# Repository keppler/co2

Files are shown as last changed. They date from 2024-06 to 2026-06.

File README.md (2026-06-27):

# CO₂-Sensor für Höhlen



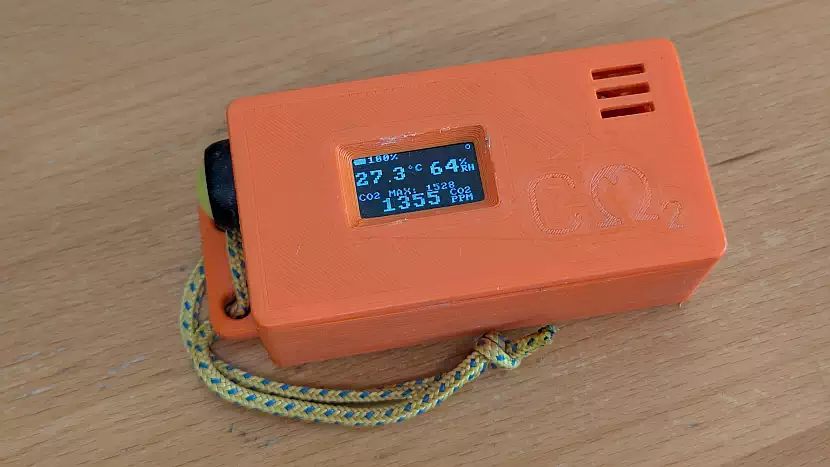
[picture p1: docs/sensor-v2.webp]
fertiger CO₂-Sensor


## Hintergrund

Kohlenstoffdioxid (_CO₂_) spielt bei der Entstehung von Höhlen eine zentrale Rolle. In Wasser gelöst - als Kohlensäure
(_H₂CO₃_) - kann es Kalk aufnehmen und somit Hohlräume entstehen lassen. Anders herum wachsen Tropfsteine, wenn mit
Kalziumkarbonat gesättigte Kohlensäure in einem Hohlraum wieder _CO₂_ an die Umgebungsluft abgibt und sich der
überschüssige Kalk absetzt. Unterirdische Wasserläufe können unter bestimmten Bedingungen ebenfalls _CO₂_ einbringen,
auch biologische und chemische Prozesse können unter Tage _CO₂_ erzeugen.

## Problem

Kohlenstoffdioxid ist ein geruchs-, geschmacks- und farbloses Gas. Zu hohe Konzentrationen sind für den menschlichen
Körper lebensgefährlich. In einigen Höhlen können sich - je nach Bewetterung, Vegetation und Jahreszeit - durchaus
bedrohliche _CO₂_-Konzentrationen bilden. In den meisten betroffenen Höhlen ist eine eventuelle _CO₂_-Problematik
bekannt und in der Regel wird auf Höhlenplänen oder vor Ort darauf hingewiesen. Befährt man jedoch eine bis dato
unbekannte Höhle oder möchte die tatsächlichen Werte messen, ist es gut, ein entsprechendes Messgerät zu haben. :-)

Handelsübliche (günstige) _CO₂_-Messgeräte für die Raumluftqualität messen nur bis 2.000 oder 5.000 ppm (0,2% bzw. 0,5%).
In entsprechenden Höhlen sind Werte über 20.000 ppm (2%) aber keine Seltenheit. Rettungskräfte, Berg- und
Industriearbeiter nutzen professionelle _CO₂_-Warngeräte (z.B. _Dräger Pac® 8000_ oder _CO2Meter PRO-10_) - für Privatpersonen sind diese aber
schwer erhältlich und zudem ziemlich kostspielig. Der häufig durchgeführte "Flammentest" (mit Feuerzeug prüfen ob eine
Flamme erzeugt werden kann) ist viel zu ungenau und zu gefährlich - eine Flamme erlöscht meist erst unter 16% Sauerstoff,
was schon auf eine _CO₂_-Konzentration von >50.000 ppm hindeuten kann!

## Lösung

Die hier vorgestellte Schaltung soll eine günstige Messung der Kohlenstoffdioxid-Konzentration auch in hohen
Bereichen ermöglichen - zuverlässiger als ein "Flammen-Test", und dennoch bezahlbar.

> [!CAUTION]
> Der Sensor darf dennoch nur als **zusätzlicher** Indikator angesehen werden! Die üblichen Anzeichen eines zu hohen
> _CO₂_-Gehalts müssen unabhängig davon beobachtet werden. Machen Sie Ihr Leben nicht von der korrekten Funktion eines
> einzelnen Sensors abhängig!  
> Zudem ersetzt diese Schaltung unter keinen Umständen ein professionelles Messgerät, das regelmäßig gewartet und
> kalibriert wird!

### Der Sensor

In den letzten Jahren hat sich in der Entwicklung von _CO₂_-Sensoren viel getan - nicht zuletzt aufgrund der
Corona-Pandemie. Der Sensor [SCD41](https://sensirion.com/de/produkte/katalog/SCD41) der Schweizer _Sensirion AG_ nutzt
das photo-akustische NDIR-Verfahren, um auf kleinstem Raum (rund 10x10x6 mm) den Anteil von _CO₂_-Molekülen in der
Umgebungsluft zu bestimmen.
Sofern die Membran des Sensors nicht zu stark verschmutzt wird, ist der Sensor technisch bedingt äußerst lange haltbar.
Die regelmäßige Kalibrierung kann automatisch anhand des _CO₂_-Gehalts in freier Umgebung erfolgen (etwa 400 ppm).

### Der Mikrocontroller

Als Mikrocontroller zur Ansteuerung des Sensors und des Displays dient ein simpler [ATtiny85](https://www.microchip.com/en-us/product/attiny85). Dieser ist robust,
günstig, gut verfügbar und mit vergleichsweise einfachen Mitteln programmierbar. Nutzt man seinen Funktionsumfang
voll aus, kann dieser ohne weitere Hilfsmittel auch die Batteriespannung messen und benötigt im Standby weniger
Strom als die Selbstentladung der Batterie.

### Das Display

Zur Anzeige dient ein schlichtes OLED-Display vom Typ _SSD1306_. Auch dieses ist günstig, gut verfügbar und einfach
zu programmieren. Zudem ist das Display - wie der Sensor auch - über einen I²C-Bus ansteuerbar, was die Verdrahtung
dramatisch vereinfacht.

## Die Schaltung

### Variante "Minimalistisch"

Für den ersten Prototypen reicht eine simple Lochrasterplatine, da im Prinzip nur die Stromversorgung und der I²C-Bus
vom Controller zum Sensor und Display (parallel) durchverdrahtet werden müssen:

<!-- ![Bild des ersten Sensor-Prototypen im Einsatz](https://github.com/keppler/co2/raw/master/docs/sensor.webp) -->

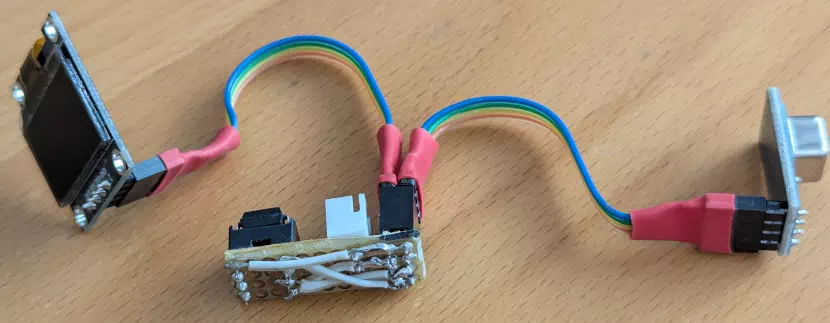
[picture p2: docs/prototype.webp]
einfacher Prototyp


### Variante "Komfort" (Version 1.3)

Die "Komfort-Schaltung" nutzt darüber hinaus noch die restlichen Pins, um einen Piezo-Piepser zur Alarmierung sowie
eine Taste zur Konfiguration zu integrieren. Hierfür wurde eine Platine gestaltet, um alle Komponenten ordentlich
zu platzieren.

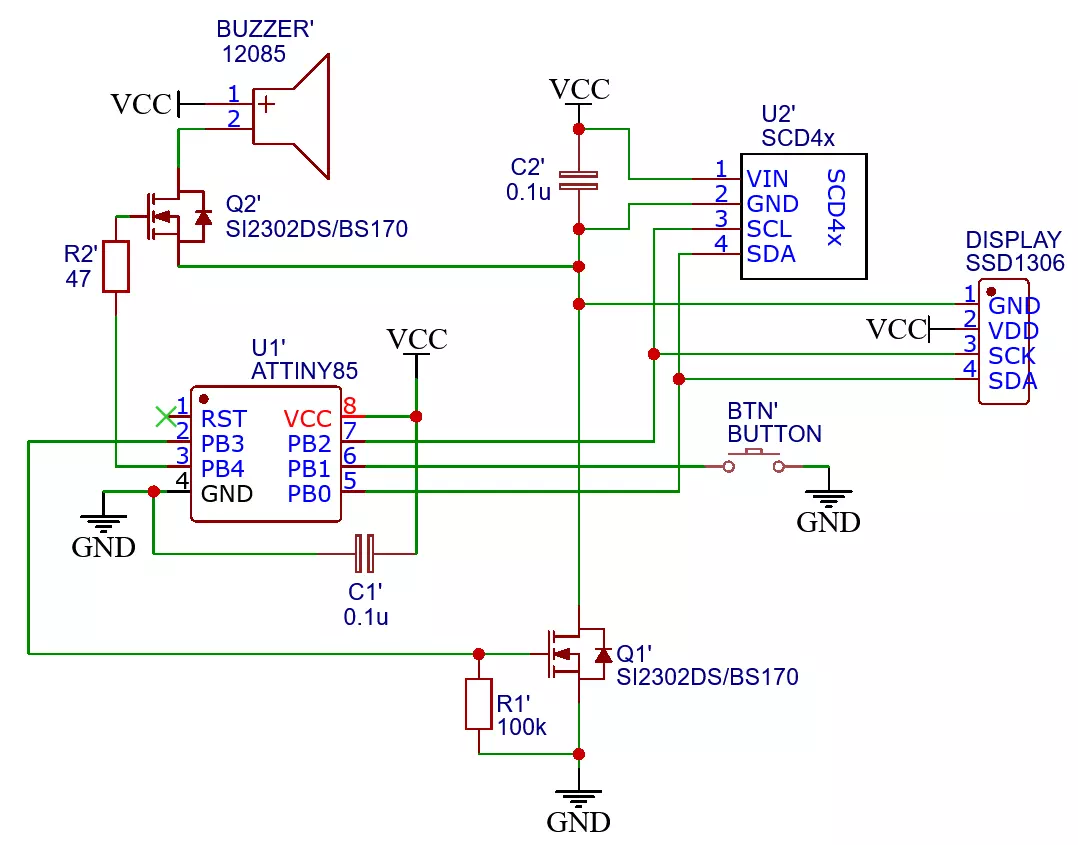
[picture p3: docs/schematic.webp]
Schaltplan


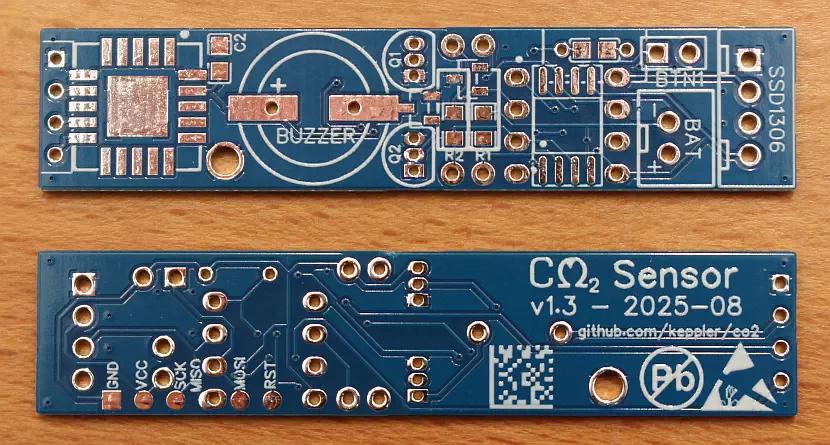
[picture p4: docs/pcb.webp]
Platine


Die Platine kann per SMD oder "klassisch" mit Lötkolben bestückt werden.

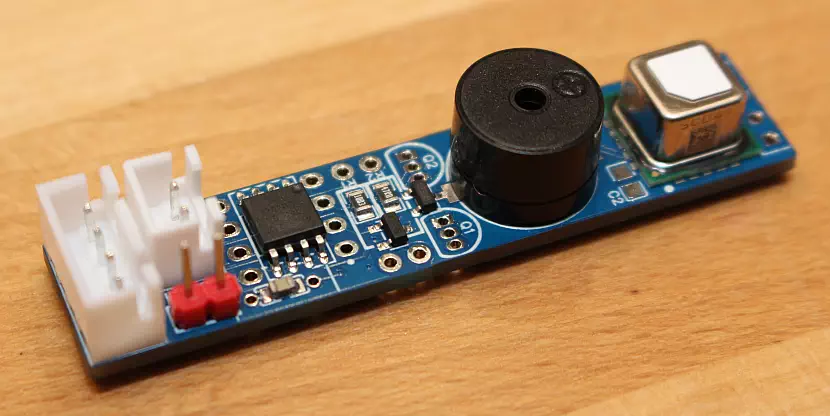
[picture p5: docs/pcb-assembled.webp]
SMD-bestückte Platine


### Bauteilliste

| Bezeichnung | Bauteil |
|---|---|
| U1 | ATtiny85 |
| U2 | SCD41 |
| Q1, Q2 | SI2302DS oder BS170 |
| R1 | Widerstand 100kΩ |
| R2 | Widerstand 47Ω |
| C1 | Kondensator 0.1µF |
| C2 | _entfällt_ |
| DISPLAY | 0,96" OLED-Display SSD1306 (I²C!) |
| BUZZER | 12x8.5mm passive Buzzer Typ 12085 |

### Bezugsquellen

Nahezu alle Teile sind bei jedem gut sortierten Elektronikdistributor bestellbar, die meisten Teile lassen sich auch
über eBay oder AliExpress besorgen. Nur beim Sensor sollte man etwas aufpassen: bei AliExpress werden diese sowohl "lose"
als auch auf kleinen Breakout-Platinen für rund $20 verkauft. Ich habe ein halbes Dutzend solcher Sensoren von
verschiedenen AliExpress-Händlern gekauft - interessanterweise hatten alle _keine_ aufgelaserte Seriennummer. Es wird
vermutet, dass es sich hierbei um Exemplare handelt, die aus anderen Produkten/Schaltungen ausgebaut wurden. Auch diese
Sensoren lieferten plausible Daten (ich glaube also nicht dass das "Kopien" sind), aber da es kaum eine Ersparnis
gegenüber einem offiziellen Distributor gibt, würde ich da eher die Finger von lassen.

Die Platine kann man sich mit den hier im Repository hinterlegten Gerber-Dateien bei jedem beliebigen Auftragsfertiger
erstellen lassen, z.B. bei JLCPCB oder Elecrow.

Ich habe normalerweise immer die eine oder andere Platine "übrig" - ein offizieller Verkauf ist aufgrund der Elektronikregulierung
aber nicht möglich. Bei Interesse bitte kurze Mail an `klaus (at) fund-ev.de`.

### Gehäuse

Ein passendes Gehäuse kann bequem mit einem 3D-Drucker erstellt werden, die `.stl`-Druckdateien liegen im Verzeichnis `case/`. PLA-Filament ist meistens völlig ausreichend, ABS ist natürlich robuster (aber auch schwieriger zu drucken).

Das Display kann am Deckel verschraubt werden, hierzu vier Gewindeeinsätze (M2.5x3) in die vorbereiteten Löcher einschmelzen. Die Platine kann ebenfalls per Schraube am Boden fixiert werden, leider ist das Loch etwas zu klein geraten - daher wird hier ein M2-Gewindeeinsatz (M2x3 oder M2x4) benötigt.

Wird der Deckel häufiger mal abgenommen, neigt leider das Kabel vom Display zur Platine zu Kabelbrüchen (vor allem am Display-Ende). Ich empfehle hierfür eine dünne **Silikon-Litze** zu verwenden (z.B. [diese: 4P, 26AWG](https://www.aliexpress.com/item/1005011606377608.html?spm=a2g0o.order_list.order_list_main.10.5cd65c5fmp5Ztc)).

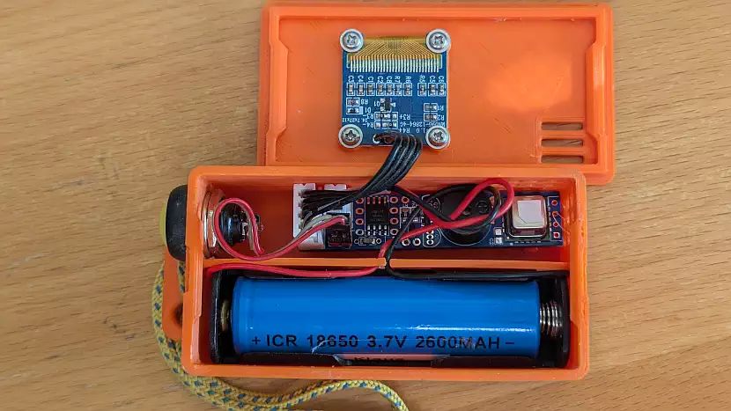
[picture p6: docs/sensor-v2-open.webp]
geöffnetes Gehäuse


## Die Software

Zum Compilieren werden die AVR-Toolchain und CMake benötigt. Alternativ kann ein fertig compiliertes Binary auch hier
aus dem Repository heruntergeladen werden.

Das Flashen erfolgt mit folgendem Befehl (ggf. angepasst an den verwendeten Programmer):

```console
avrdude -c usbasp -p t85 -P usb -v \
  -U lfuse:w:0x62:m -U hfuse:w:0xd7:m -U efuse:w:0xff:m \
  -U flash:w:co2-scd41.hex:i \
  -U eeprom:w:co2-scd41.eep:i
```

Aktuell belegt die Software mit 8.100 Bytes fast den gesamten verfügbaren Speicher, somit ist ohne größere Tricks
vorerst keine nennenswerte Erweiterung der Funktionalität möglich.
Anders formuliert: die verfügbaren Ressourcen werden optimal ausgenutzt. :-)

Die Programmierung kann "in system" erfolgen, auf der Rückseite der Platine sind Pads zum Anlöten oder für Pogo-Pins
vorbereitet.

## Bedienungsanleitung

Nach dem Anschluss an die Stromversorgung oder dem Wiedereinschalten per Taster startet der Sensor:
der Piezo-Piepser wird kurz getestet sowie die Batteriespannung ausgelesen und angezeigt.
Anschließend wechselt die Software in die automatische Messung. Die Daten
werden alle 5 Sekunden aktualisiert, der höchste gemessene CO₂-Wert wird dauerhaft angezeigt.  
Da stabile Messdaten erst nach etwa 90 Sekunden zur Verfügung stehen, werden die Daten in dieser Zeit zusammen mit
einem Countdown farblich abgesetzt ("ausgegraut") angezeigt.

Jedes Mal wenn der Sensor eine weitere 2.000 ppm-Schwelle überschreitet, gibt dieser ein akustisches Signal aus.
Ab 10.000 ppm piepst er dann je 2x, ab 20.000 ppm 3x und ab 24.000 ppm 4x. Wird eine Schwelle für mehr als 60 Sekunden um
mehr als 2.000 ppm wieder unterschritten, gibt es einen kurzen Ton zur "Entwarnung".

Der Button unterscheidet zwischen kurzer Betätigung (>50ms) und langer Betätigung (>1s). In den meisten Fällen wird ein
kurzer Drücker zur Auswahl und ein langer Drücker zur Bestätigung genutzt.

Aus der Messung heraus erreicht man über einen kurzen Drücker das Menü:

- **`AUTO-CALIB: [ON|OFF]`**: Auto-Kalibrierung ein-/ausschalten. Bei aktivierter Autokalibrierung geht der Sensor
  davon aus, dass der niedrigste innerhalb von sieben Tagen gemessene Wert einer CO₂-Konzentration von 400ppm entspricht.  
  **Es wird empfohlen, die Auto-Kalibrierung zu deaktiveren und den Sensor regelmäßig manuell zu kalibrieren!**
- **`FORCE CALIBRATE`**: Kalibrierung mit einer CO₂-Konzentration von 420ppm (Außenluft) erzwingen. Wichtig ist hierfür, dass der Sensor seit mindestens 3 Minuten durchgehend an der Außenluft betrieben wird.
- **`ALTITUDE: xxx`**: Einstellung der Höhe (verbessert die Genauigkeit der CO₂-Messung). Kann in 100m-Schritten von
  0-3000m eingestellt werden, die Einstellung wird dauerhaft im Sensor gespeichert.
- **`SELF TEST`**: Selbsttest des SCD41-Sensors ausführen. Dieser Vorgang dauert 10 Sekunden und sollte eigentlich immer `OK` zurückgeben.
- **`VOLUME`**: Einstellung der Piepser-Lautstärke (0=aus, 1=laut, 2=mittel, 3=leise; Standard=3).
- **`POWER OFF`**: Gerät ausschalten. Im Standby benötigt die Schaltung nur 210nA/0.2µA (das liegt weit unterhalb der Selbstentladung der Batterie). Mit einen langen Tastendruck kann man den Sensor wieder einschalten.
- **`BACK`**: zurück zur Messung (erfolgt ansonsten auch automatisch nach 10 Sekunden)

### Inbetriebnahme

Vor der ersten Verwendung sollten folgende Schritte durchgeführt werden:
- Auto-Kalibrierung deaktivieren
- barometrische Höhe einstellen
- Sensor mind. 3 Minuten an der Außenluft betreiben, anschließend manuelle Kalibierung durchführen

## Ausblick

Inspiriert von dieser Schaltung gibt es noch einen "großen Bruder": die Version 2 dieses Geräts kann die gemessenen
Daten bis zu 22 Stunden lang minütlich aufzeichnen und wahlweise per NFC oder Bluetooth Low Energy (BLE) an ein
Android-Smartphone übermitteln. Ein zusätzlich integrierter Sensor sorgt zudem für exakte Luftdruck-, Temperatur-
und Luftfeuchtigkeitsdaten, eine automatische barometrische Kompensation verbessert die Genauigkeit der
_CO₂_-Daten.  
Sowohl dessen Schaltung als auch die Software sind aber um ein Vielfaches komplexer. Bei Interesse bitte kurze Mail.

### Langzeitbetrieb / Datenlogger

Es kommt immer wieder mal die Frage auf, ob auch eine automatisierte _CO₂_-Messung über einen längeren Zeitraum möglich ist.

Das Problem hierbei ist inzwischen weniger die Stromversorgung als vielmehr der sogenannte "Drift" des Sensors.
Laut Hersteller sollte der SCD41 regelmäßig (am besten automatisch etwa einmal wöchentlich) kalibriert werden.

Es gibt aber auch photo-optische Sensoren mit einer separaten Messkammer zur Drift-Kompensation, wie z.B. den
[Sensirion SCD30](https://sensirion.com/de/produkte/katalog/SCD30) oder den
[E+E EE895](https://www.epluse.com/de/produkte/co2-messung/co2-module-und-fuehler/ee895/). Diese dürften für solche
Zwecke wesentlich besser geeignet sein. Hohe Luftfeuchtigkeit oder _CO₂_-Konzentrationen > 10.000 ppm können
aber auf Dauer auch ein Problem darstellen.

Ein Datenlogger-Prototyp ist derzeit in Vorbereitung - da aber auch Referenzmessungen über längere Zeiträume stattfinden
müssen wird das alles noch ein wenig dauern.

### Alternative Ansätze

Ein anderer Ansatz ist, ein ESP32-Board mit integriertem Display zu verwenden, z.B. ein _TTGO T-Display_.
Der Code kann mit der _Arduino IDE_ entwickelt und bequem geflashed werden, den Sensor schließt man direkt an die
Pins des Board an. Beispiele hierzu gibt es z.B. unter https://emariete.com/en/co2-meter-gadget/

Ein solches Board benötigt im Betrieb allerdings wesentlich mehr Strom als ein einzelner, kleiner Mikrocontroller.
Diese Variante ist also insbesondere dann interessant, wenn entweder Strom keine Rolle spielt (weil der Einsatz
auf wenige Stunden begrenzt ist), oder man bereits mit dem Arduino-Ökosystem vertraut ist.

### Weiterführende Informationen

- Smith, Garry K. (2003): Carbon Dioxide in Limestone Caves and its Effect on Cavers.  
  British Cave Research Association, Speleology 3 pp10-12.
  https://bcra.org.uk/pub/docs/downloads.html?f=sp003010.f
- Bad Air in Caves  
  https://www.youtube.com/watch?v=hUKdhmzOqtQ

## ToDo

Stand: 27.06.2026

- [ ] Bekannter Fehler: nach starken Erschütterungen *kann* es sein, dass die Messung "festhängt", also trotz Animation keine Daten aktualisiert.
      Der Code wird in Kürze entsprechend angepasst, so dass nach mehreren identischen Messungen ein Sensor-Reset ausgelöst wird.

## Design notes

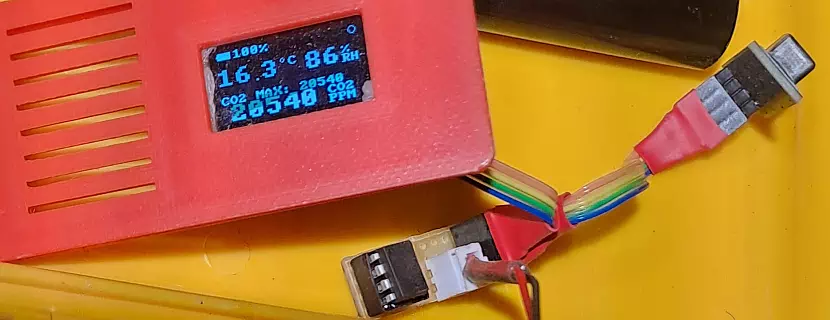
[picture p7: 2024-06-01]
docs/sensor.webp

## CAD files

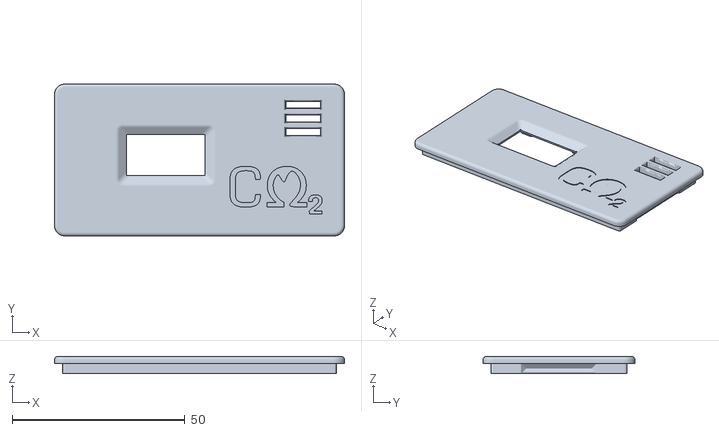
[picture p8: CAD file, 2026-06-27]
case/co2 Sensor Case - Body.stl
84.0 x 44.0 x 5.00

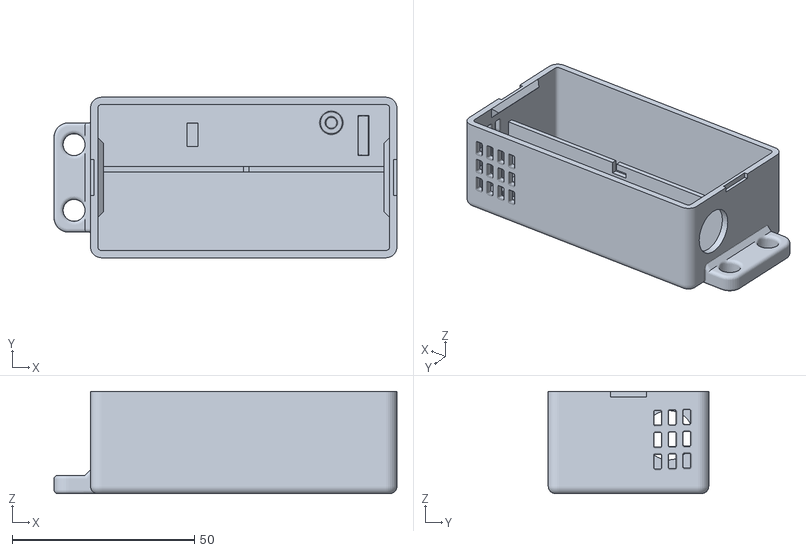
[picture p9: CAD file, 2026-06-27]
case/co2 Sensor Case - Cover.stl
94.0 x 44.0 x 28.0

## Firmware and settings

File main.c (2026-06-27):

/*         ___    ___
 *  __ ___|_  )__/ __| ___ _ _  ___ ___ _ _
 * / _/ _ \/ /___\__ \/ -_) ' \(_-</ _ \ '_|
 *_\__\___/___|  |___/\___|_||_/__/\___/_|_________________________________
 * CO₂ Sensor for Caving -- https://github.com/keppler/co2
 * Program entry and main measurement loop
 */

#include <avr/pgmspace.h>
#include <util/delay.h>
#include "beep.h"
#include "button.h"
#include "i2cmaster.h"
#include "menu.h"
#include "splash.h"
#include "timer.h"
#include "SSD1306.h"
#include "SCD4x.h"
#include "VCC.h"
#include "main.h"

#define VCC_MIN 280 /* minimum voltage: 2.80V */
#define VCC_MAX 370 /* maximum voltage: 3.70V */

const char app_version[] PROGMEM = "V35 - 2026-06-27";

// show battery status
static uint8_t oldPct = 0;
static uint8_t vccPct = 0;
static void writeBattery(uint8_t pct) {
    if (oldPct == pct) return; /* nothing has changed */
    oldPct = pct;
    /* uint8_t img[] = {0x18, 0x7e, 0x42, 0x42, 0x7e, 0x7e, 0x7e, 0x7e, 0x7e, 0x7e, 0x7e, 0x7e, 0x7e}; */
    uint8_t img[13];
    img[0] = 0x18;
    img[1] = img[12] = 0x7e;
    for (uint8_t x=0; x<10; x++) {
        img[11-x] = pct > x*10 ? 0x7e : 0x42;
    }
    SSD1306_writeImg(0, 0, 13, 8, img, 0);
    uint8_t x = SSD1306_writeInt(2, 0, pct, 10, 0x00, 0);
    SSD1306_writeChar(x++, 0, '%', 0);
    while (x < 6) SSD1306_writeChar(x++, 0, ' ', 0);
}

static uint8_t tick;
static uint16_t co2max = 0;
static uint16_t lastThreshold = 2000;
static uint8_t belowThresholdSecs = 0;

typedef enum {
    MAIN_STATE_EMPTY,
    MAIN_STATE_STARTING,
    MAIN_STATE_RUNNING,
} main_state_t;
static main_state_t main_state = MAIN_STATE_EMPTY;

static void main_enter(void) {
    tick = 0;
    SSD1306_clear();

    if (SCD4x_startPeriodicMeasurement() != 0) {
        SSD1306_writeString(0, 2, PSTR("START ERROR"), 1);
    }

    oldPct = 0xff; // force update
    writeBattery(vccPct);

    main_state = MAIN_STATE_EMPTY;
}

static void main_leave(void) {
    SCD4x_stopPeriodicMeasurement();
}

static void main_loop(void) {
    static const char tickChars[] = {'<','=','>','='};
    static uint64_t old_ms = 0;
    uint8_t err;

    uint8_t btn = button_pressed();
    if (btn == 1) {
        app_state_next(MENU);
        return;
    }

    if (timer_millis() - old_ms >= 1000) {
        if (main_state == MAIN_STATE_STARTING) {
            SSD1306_writeInt(6, 5, 90 - (timer_millis() / 1000), 10, 0, 2);
        }
        err = SCD4x_getData();
        if (err == 0) {
            if (main_state == MAIN_STATE_EMPTY) {
                SSD1306_writeString(4, 3, PSTR("."), 1);
                SSD1306_writeString(7, 2, PSTR("[C"), 1);   /* '[' is displayed as '°' */
                SSD1306_writeString(14, 2, PSTR("%"), 1);
                SSD1306_writeString(14, 3, PSTR("RH"), 1);

                if (main_state == MAIN_STATE_RUNNING || timer_millis() > 90000) {
                    SSD1306_writeString(0, 5, PSTR("CO2 MAX:"), 1);
                    SSD1306_writeInt(9, 5, co2max, 10, 0, 0);
                } else {
                    SSD1306_writeString(0, 5, PSTR("INIT:"), 1);
                    SSD1306_writeInt(6, 5, 90 - (timer_millis() / 1000), 10, 0, 2);
                }
                SSD1306_writeString(12, 6, PSTR("CO2"), 1);
                SSD1306_writeString(12, 7, PSTR("PPM"), 1);
                main_state = MAIN_STATE_STARTING;
            }
            if (main_state == MAIN_STATE_RUNNING || timer_millis() > 90000) {
                if (main_state == MAIN_STATE_STARTING) SSD1306_writeString(0, 5, PSTR("CO2 MAX:"), 1);
                main_state = MAIN_STATE_RUNNING;
            }

            if (main_state == MAIN_STATE_RUNNING) {
                if (SCD4x_VALUE_co2 > co2max) co2max = SCD4x_VALUE_co2;
                SSD1306_writeInt(9, 5, co2max, 10, 0, 0);
            }
            uint8_t flags = SSD1306_FLAG_DOUBLE;
            if (main_state == MAIN_STATE_STARTING) flags |= SSD1306_FLAG_LIGHT;
            SSD1306_writeInt(1, 6, SCD4x_VALUE_co2, 10, flags, 5);
            SSD1306_writeInt(0, 2, SCD4x_VALUE_temp / 10, 10, flags, 2);
            SSD1306_writeInt(5, 2, SCD4x_VALUE_temp % 10, 10, flags, 0);
            SSD1306_writeInt(10, 2, SCD4x_VALUE_humidity, 10, flags, 2);

            /* check threshold */
            if (SCD4x_VALUE_co2 > lastThreshold + 2000) {
                /* beep. */
                // ... 6000-8000: 1x, 10.000-18.000: 2x, 20.000-24.000 3x, >=24.000: 4x
                uint8_t cnt = 1;
                if (SCD4x_VALUE_co2 >= 10000) cnt++;
                if (SCD4x_VALUE_co2 >= 20000) cnt++;
                if (SCD4x_VALUE_co2 >= 24000) cnt++;
                while (cnt-- > 0) {
                    beep(BEEP_WARN);
                    _delay_ms(200);
                }

                /* update threshold - use 2000ppm steps */
                lastThreshold = SCD4x_VALUE_co2 - (SCD4x_VALUE_co2 % 2000);
            } else if (SCD4x_VALUE_co2 < lastThreshold - 2000) {
                if (belowThresholdSecs > 0) {
                    belowThresholdSecs -= 5;    /* remember: we have one valid measurement every five seconds! */
                    if (belowThresholdSecs == 0) {
                        /* if less than last threshold for more than 60sec, reduce threshold by 2000ppm */
                        if (lastThreshold >= 6000) lastThreshold -= 2000;
                        beep(BEEP_RELAX);
                    }
                }
            } else {
                /* within range of lastThreshold +/- 1999, reset reduce counter */
                belowThresholdSecs = 60;
            }
        } else if (err != 0xFF) {
            /* ignore case of 0xff (no data available) */
            SSD1306_writeString(0, 3, PSTR("ERR:       "), 1);
            SSD1306_writeInt(5, 3, err, 16, 0x00, 0);
        }
        if (tick % 10 == 0) {
            /* update VCC display every ~10 seconds */
            uint16_t vcc = VCC_get();
            if (vcc < VCC_MIN) vcc = VCC_MIN;
            else if (vcc > VCC_MAX) vcc = VCC_MAX;
            vccPct = ((vcc - VCC_MIN) * 100) / (VCC_MAX - VCC_MIN);
            writeBattery(vccPct);
        }
        SSD1306_writeChar(15, 0, tickChars[++tick % 4], 0);
        old_ms = timer_millis();
    }

}

static enum app_state_t app_state = MAINLOOP, app_lastState = MAINLOOP;

void app_state_next(enum app_state_t next) {
    app_lastState = app_state;
    app_state = next;
}

void app_wakeup(uint8_t initial) {
    uint8_t err;

    /* initialize display */
    SSD1306_init();
    SSD1306_clear();
    SSD1306_on();

    SSD1306_writeImg(5, 1, splash_width, splash_height, splash_data, 2);
    SSD1306_writeString(0, 5, app_version, SSD1306_FLAG_PGM);

    /* beep. */
    beep(BEEP_STARTUP);

    if ((err = SCD4x_stopPeriodicMeasurement()) != 0) {
        SSD1306_writeInt(14, 0, err, 16, 0x00, 0);
    }

    /* detect sensor type */
    scd4x_sensor_type_t sensorType = SCD4x_getSensorType();
    if (sensorType == SCD4x_SENSOR_SCD40) {
        SSD1306_writeString(0, 6, PSTR("SCD40"), 1);
    } else if (sensorType == SCD4x_SENSOR_SCD41) {
        SSD1306_writeString(0, 6, PSTR("SCD41"), 1);
    } else if (sensorType == SCD4x_SENSOR_ERROR) {
        SSD1306_writeString(0, 6, PSTR("ERROR"), 1);
        while(1);
    } else {
        SSD1306_writeString(0, 6, PSTR("UNKNW"), 1);
        while(1);
    }

    {
        SSD1306_writeString(7, 6, PSTR("VCC 0.00V"), 1);
        uint16_t vcc = VCC_get();
        uint8_t x;
        x = SSD1306_writeInt(11, 6, vcc / 100, 10, 0x00, 0);
        //SSD1306_writeChar(x++, 5, '.', 0x00);
        x = SSD1306_writeInt(++x, 6, vcc % 100, 10, SSD1306_FLAG_FILL_ZERO, 2);
        //SSD1306_writeChar(x++, 5, 'V', 0x00);
    }

/* disabled display of serial number to save precious memory on ATtiny85 */
#if 0
    /* read serial number */
    if (initial) {
        uint8_t serial[6];
        if ((err = SCD4x_getSerialNumber(serial)) != 0) {
            /* error while reading serial */
            SSD1306_writeString(0, 7, PSTR("CRC ERROR"), 1);
        } else {
            uint8_t i;
            for (i=0; i<3; i++) {
                uint8_t u = serial[i*2];
                if (u < 0x10) {
                    SSD1306_writeInt(i*5, 7, 0, 16, 0x00, 0);
                    SSD1306_writeInt((i*5)+1, 7, u, 16, 0x00, 0);
                } else {
                    SSD1306_writeInt(i*5, 7, u, 16, 0x00, 0);
                }
                u = serial[(i*2)+1];
                if (u < 0x10) {
                    SSD1306_writeInt((i*5)+2, 7, 0, 16, 0x00, 0);
                    SSD1306_writeInt((i*5)+3, 7, u, 16, 0x00, 0);
                } else {
                    SSD1306_writeInt((i*5)+2, 7, u, 16, 0x00, 0);
                }
            }
        }
    }
#endif

    /* reset max and threshold values after power-off */
    lastThreshold = 2000;
    belowThresholdSecs = 0;
    co2max = 0;

    _delay_ms(3000);
}

int main(void) {
    /* PB3: sensor power */
    DDRB |= (1 << DDB3);    /* set port mode to OUTPUT */
    PORTB |= (1 << PB3);    /* set ON */

    /* initialize time functions */
    timer_init();

    button_init();

    /* init sound transducer */
    beep_init();

    /* initialize I²C bus */
    i2c_init();

    app_wakeup(1);

    main_enter();

    for (;;) {
        button_read();
        if (app_lastState != app_state) {
            // state transition
            switch (app_lastState) {
                case MAINLOOP: main_leave(); break;
                default: break;
            }
            switch (app_state) {
                case MAINLOOP: main_enter(); break;
                case MENU: menu_enter(); break;
            }
            app_lastState = app_state;
        }
        switch (app_state) {
            case MAINLOOP: main_loop(); break;
            case MENU: menu_loop(); break;
        }

    }
}

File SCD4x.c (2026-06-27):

/*         ___    ___
 *  __ ___|_  )__/ __| ___ _ _  ___ ___ _ _
 * / _/ _ \/ /___\__ \/ -_) ' \(_-</ _ \ '_|
 *_\__\___/___|  |___/\___|_||_/__/\___/_|_________________________________
 * CO₂ Sensor for Caving -- https://github.com/keppler/co2
 * Minimalistic (optimized) access to SCD40/SCD41 CO₂ sensor
 * Datasheet: https://sensirion.com/media/documents/48C4B7FB/64C134E7/Sensirion_SCD4x_Datasheet.pdf
 * Copyright (c) 2024 Klaus Keppler - https://github.com/keppler/co2
 */

#include <stddef.h>
#include <util/delay.h>
#include "SCD4x.h"
#include "i2cmaster.h"

#define SCD4x_ADDRESS ((0x62) << 1)

#define SCD4x_COMMAND_GET_FEATURE_SET_VERSION                 0x202F // execution time: 1ms
#define SCD4x_COMMAND_START_PERIODIC_MEASUREMENT              0x21b1 // execution time: 0ms
#define SCD4x_COMMAND_STOP_PERIODIC_MEASUREMENT               0x3f86 // execution time: 500ms
#define SCD4x_COMMAND_GET_SERIAL_NUMBER                       0x3682 // execution time: 1ms
#define SCD4x_COMMAND_GET_DATA_READY_STATUS                   0xe4b8 // execution time: 1ms
#define SCD4x_COMMAND_READ_MEASUREMENT                        0xec05 // execution time: 1ms
#define SCD4x_COMMAND_GET_SENSOR_ALTITUDE                     0x2322 // execution time: 1ms
#define SCD4x_COMMAND_SET_SENSOR_ALTITUDE                     0x2427 // execution time: 1ms
#define SCD4x_COMMAND_GET_AUTOMATIC_SELF_CALIBRATION          0x2313 // execution time: 1ms
#define SCD4x_COMMAND_SET_AUTOMATIC_SELF_CALIBRATION          0x2416 // execution time: 1ms
#define SCD4x_COMMAND_PERFORM_FORCED_RECALIBRATION            0x362f // execution time: 400ms
#define SCD4x_COMMAND_PERFORM_SELF_TEST                       0x3639 // execution time: 10000ms
#define SCD4x_COMMAND_POWER_DOWN                              0x36e0 // execution time: 1ms
#define SCD4x_COMMAND_WAKE_UP                                 0x36f6 // execution time: 20ms
#define SCD4x_COMMAND_PERSIST_SETTINGS                        0x3615 // execution time: 800ms

uint16_t SCD4x_VALUE_co2 = 0;
int16_t SCD4x_VALUE_temp = 0;
uint8_t SCD4x_VALUE_humidity = 0;

static uint8_t _computeCRC8(const uint8_t *data, uint8_t len) {
    uint8_t crc = 0xFF; // initialize with 0xff

    for (uint8_t x = 0; x < len; x++) {
        crc ^= data[x]; // XOR-in the next input byte
        for (uint8_t i = 0; i < 8; i++) {
            if ((crc & 0x80) != 0) {
                crc = (uint8_t)((crc << 1) ^ 0x31);
            } else {
                crc <<= 1;
            }
        }
    }

    return crc;
}

// Gets two bytes from SCD4x plus CRC.
// Returns true if endTransmission returns zero _and_ the CRC check is valid
static uint8_t _readRegister(uint16_t registerAddress, const uint16_t *data, uint8_t dataCount, uint16_t *response, uint8_t responseCount, uint16_t delayMillis) {
    uint8_t buf[2];

    i2c_start_wait(SCD4x_ADDRESS + I2C_WRITE);
    i2c_write(registerAddress >> 8);   // MSB
    i2c_write(registerAddress & 0xFF); // LSB

    // send data (if given)
    for (uint8_t i=0; i < dataCount && data != NULL; i++) {
        buf[0] = data[i] >> 8;      // MSB
        buf[1] = data[i] & 0xFF;    // LSB
        i2c_write(buf[0]);
        i2c_write(buf[1]);
        i2c_write(_computeCRC8(buf, 2)); // CRC
    }
    /* stopping in all cases, see line 87ff for full explanation */
    i2c_stop();

    while (delayMillis > 0) {
        /* workaround against overflow on large delays (i.e. 10000ms on self test) */
        uint16_t wait = delayMillis > 1000 ? 1000 : delayMillis;
        _delay_ms(wait);
        delayMillis -= wait;
    }

    if (response == NULL || responseCount == 0) {
        return 0;
    }

    uint8_t ret = 0;
    /* instead of i2c_rep_start(), we need to restart with i2c_start()... contrary to the SCD41 documentation,
     * the bus requires a full i2c_stop()/i2c_start() at least on very long requests like the self-test (10sec)
     * (for all "faster" commands the previous i2c_rep_start() would work though) */
    i2c_start(SCD4x_ADDRESS + I2C_READ);
    for (uint8_t i=0; i < responseCount; i++) {
        buf[0] = i2c_readAck();
        buf[1] = i2c_readAck();
        response[i] = (buf[0] << 8) | buf[1];
        uint8_t crc = i2c_read(i == responseCount-1 ? 0 : 1);   /* last read: NACK, else ACK */
        if (crc != _computeCRC8(buf, 2)) ret = 1;
    }
    i2c_stop();
    return ret;
}

uint8_t SCD4x_startPeriodicMeasurement(void) {
    return _readRegister(SCD4x_COMMAND_START_PERIODIC_MEASUREMENT, NULL, 0, NULL, 0, 0);
}

uint8_t SCD4x_stopPeriodicMeasurement(void) {
    return _readRegister(SCD4x_COMMAND_STOP_PERIODIC_MEASUREMENT, NULL, 0, NULL, 0, 500);
}

uint8_t SCD4x_getSerialNumber(uint8_t serial[6]) {
    return _readRegister(SCD4x_COMMAND_GET_SERIAL_NUMBER, NULL, 0, (uint16_t*)serial, 3, 1);
}

scd4x_sensor_type_t SCD4x_getSensorType(void) {
    /* use "GetFeatureSet" command to detect sensor type */
    uint16_t featureSet;
    if (_readRegister(SCD4x_COMMAND_GET_FEATURE_SET_VERSION, NULL, 0, &featureSet, 1, 1) != 0) {
        // error
        return SCD4x_SENSOR_ERROR;
    }
    uint8_t sensor = ((featureSet & 0x1000) >> 12);
    if (sensor == 0x00) return SCD4x_SENSOR_SCD40;
    if (sensor == 0x01) return SCD4x_SENSOR_SCD41;
    return SCD4x_SENSOR_UNKNOWN;
}

uint16_t SCD4x_getSensorAltitude(void) {
    uint16_t data;
    if (_readRegister(SCD4x_COMMAND_GET_SENSOR_ALTITUDE, NULL, 0, &data, 1, 1) != 0) {
        /* error while reading */
        return 9999;
    }
    return data;
}

void SCD4x_setSensorAltitude(uint16_t alt) {
    _readRegister(SCD4x_COMMAND_SET_SENSOR_ALTITUDE, &alt, 1, NULL, 0, 1);
}

uint8_t SCD4x_getData(void) {
    uint8_t ret;
    uint16_t data[3];
    if ((ret = _readRegister(SCD4x_COMMAND_GET_DATA_READY_STATUS, NULL, 0, data, 1, 1)) != 0) {
        /* error while reading */
        return ret;
    }
    if ((data[0] & 0x07FF) == 0) return 0xFF; /* no data available */

    /* now read data */
    if ((ret = _readRegister(SCD4x_COMMAND_READ_MEASUREMENT, NULL, 0, data, 3, 1)) != 0) {
        /* error while reading */
        return ret;
    }

    SCD4x_VALUE_co2 = data[0];
    SCD4x_VALUE_temp = ((int32_t)data[1] * 1750L / 65536L) - 450;
    int32_t h = ((int32_t)data[2]) * 100L / 65536L;
    if (h < 0) h = 0;
    if (h > 100) h = 100;
    SCD4x_VALUE_humidity = h;

    return 0;
}

scd4x_asc_enabled_t SCD4x_getAutomaticSelfCalibration(void) {
    uint16_t data;
    if (_readRegister(SCD4x_COMMAND_GET_AUTOMATIC_SELF_CALIBRATION, NULL, 0, &data, 1, 1) != 0) {
        /* error while reading, i.e. CRC error */
        return SCD4x_ASC_UNKNOWN;
    }
    switch (data) {
        case 0x00: return SCD4x_ASC_DISABLED;
        case 0x01: return SCD4x_ASC_ENABLED;
        default: return SCD4x_ASC_UNKNOWN;
    }
}

void SCD4x_setAutomaticSelfCalibration(scd4x_asc_enabled_t asc) {
    uint16_t data = asc == SCD4x_ASC_ENABLED ? 0x01 : 0x00;
    _readRegister(SCD4x_COMMAND_SET_AUTOMATIC_SELF_CALIBRATION, &data, 1, NULL, 0, 1);
}
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

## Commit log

2024-08-25 improved timing of I2C bus when running with 1MHz
2024-08-25 added more features (altitude, calibration, self-test, etc.), cleaned up & optimized code
2024-08-25 added software-debounced button driver
2024-08-25 added microseconds timer using interrupts
2024-08-25 added button, timer, configuration menu; improved code
2025-07-09 fixed power issue when using transducer, set unused pins non-floating
    [main.c]
2025-07-09 added images of current version
2025-07-30 removed usage of `float`, improved I2C code, cleaned up
2025-08-03 improved timing of I2C code for 1MHz CPU, restored "old" code for other speeds
2025-08-03 cleaned up, beep on power-up, improved power-on usability be resetting timer and button state
2025-08-03 added splash image, improved wake-up and power-down, cleaned up
2025-08-05 fixed bug in beep(), simplified melody timing
    [beep.c, main.c]
2025-11-01 fixed check for "no data available"
    [SCD4x.c]
2025-11-01 allow configuration of buzzer volume
    [beep.c]
2025-11-01 added menu option to configure buzzer volume, power-off all peripheral devices via MOSFET
2025-11-01 configure peripheral power-off pin, disabled displaying serial number
2025-11-03 updated images, added BOM, schematic and PCB gerber files
2026-06-27 added case, updated description
    [co2 Sensor Case - Body.stl, co2 Sensor Case - Cover.stl]
2026-06-27 replaced main image, added image of open case, updated README accordingly
2026-06-27 released v35 (modified I2C communication with SCD41, fixing self-test)
    [SCD4x.c, main.c]
